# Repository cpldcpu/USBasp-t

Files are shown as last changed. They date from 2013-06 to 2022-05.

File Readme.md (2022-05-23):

## micro - USBasp ##

This is a work in progress. 

* Port of USBasp to ATtiny 85
* Design of optimized hardware

Why?

* It's fun.
* USBasp is a de-facto standard for small USB-AVR programmers. It's the only one to support TPI.
* Porting it to ATtiny85 allows for a smaller and cheaper circuit. Cheaper MCU, no Xtal, etc...

This software is based on Thomas Fischl's USBasp. See readme.txt for original comments.

### Status ####

Software:

* USBasp sucessfully compiles for the ATTiny85.
* micronucleus works as a bootloader.
* USB device is recognized as USBasp and communicates with AVRdude.
* Software tested on microUSB hardware. Both TPI and SPI seem to work.

Hardware:

* Revision 0.5 sent to OSH park for pcb manufacturing.
* Update v1.1 done, ready for manufacturing.
* Update 02/08/2013: All parts received, first device built.

### Flashing

* Flash micronucleus
* Set the fuses as in thuis Makefile: HFUSE=0x5d, LFUSE=0xe1, EFUSE=0xfe
* Flash the firmware with micronucleus

### Hardware ###

Circuit:  
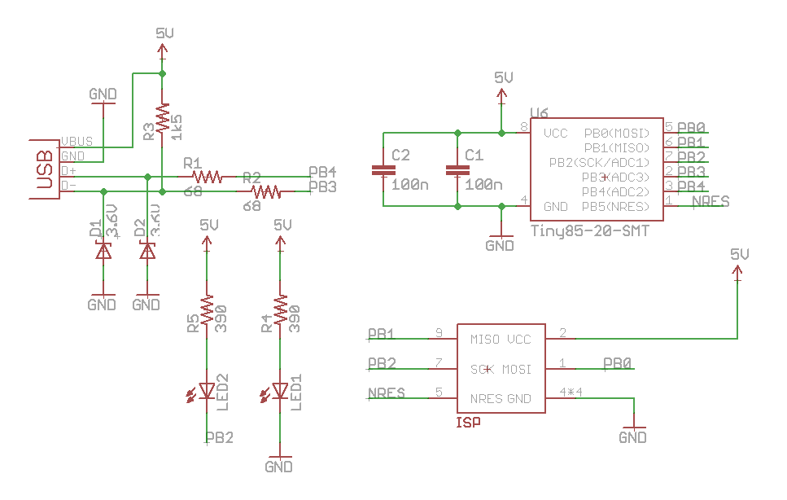
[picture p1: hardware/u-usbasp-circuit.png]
Circuit


v1.1 PCB front side:  
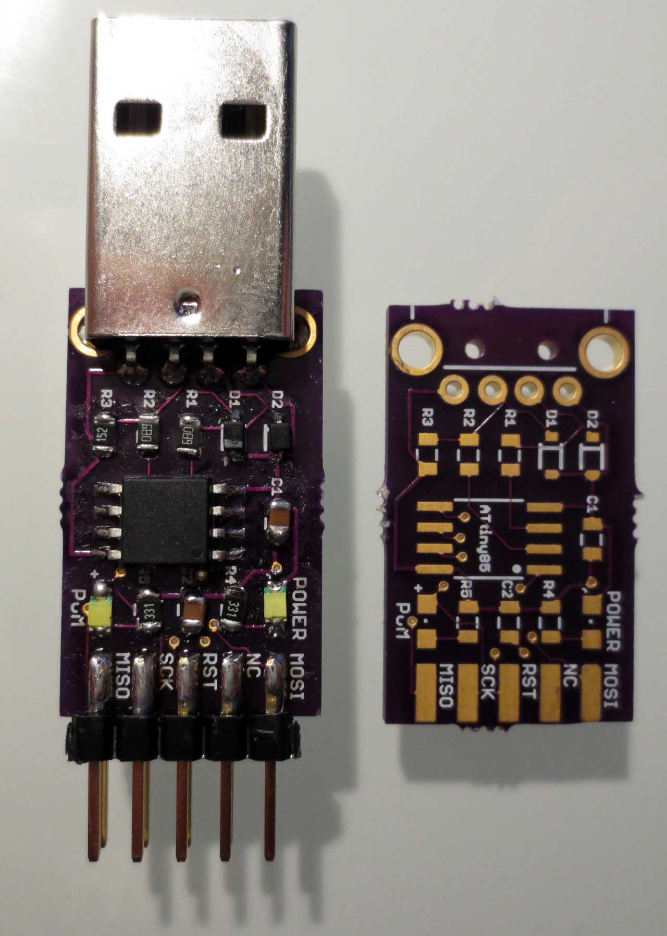
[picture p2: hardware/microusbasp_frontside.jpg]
V1.1 PCB front


v1.1 PCB rear side:   
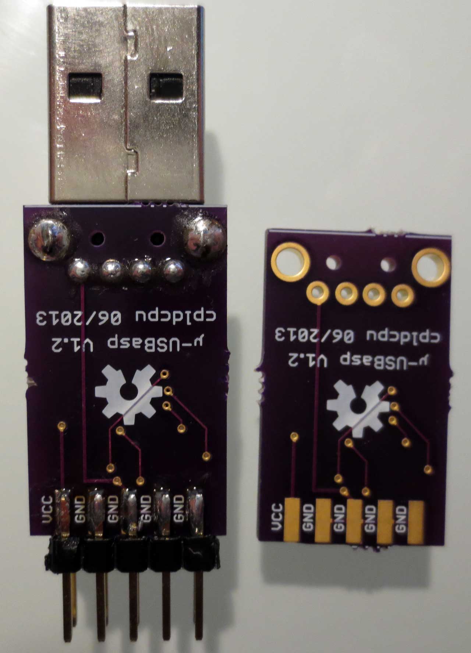
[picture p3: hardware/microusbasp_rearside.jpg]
V1.1 PCB rear


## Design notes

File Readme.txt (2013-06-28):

This is the README file for USBasp.

USBasp is a USB in-circuit programmer for Atmel AVR controllers. It simply
consists of an ATMega88 or an ATMega8 and a couple of passive components.
The programmer uses a firmware-only USB driver, no special USB controller
is needed.

Features:
- Works under multiple platforms. Linux, Mac OS X and Windows are tested.
- No special controllers or smd components are needed.
- Programming speed is up to 5kBytes/sec.
- SCK option to support targets with low clock speed (< 1,5MHz).
- Planned: serial interface to target (e.g. for debugging).

LICENSE

USBasp is distributed under the terms and conditions of the GNU GPL version
2 (see "firmware/usbdrv/License.txt" for details).

USBasp is built with V-USB driver by OBJECTIVE DEVELOPMENT GmbH. See
"firmware/usbdrv/" for further information.

LIMITATIONS

Hardware:
This package includes a circuit diagram. This circuit can only be used for
programming 5V target systems. For other systems a level converter is needed.

Firmware:
The firmware dosn't support USB Suspend Mode. A bidirectional serial
interface to slave exists in hardware but the firmware doesn't support it yet.

USE PRECOMPILED VERSION

Firmware:
Flash "bin/firmware/usbasp.atmega88.xxxx-xx-xx.hex" or
"bin/firmware/usbasp.atmega8.xxxx-xx-xx.hex" to the used controller with a
working programmer (e.g. with avrdude, uisp, ...). Set jumper J2 to activate
USBasp firmware update function.
You have to change the fuse bits for external crystal (see "make fuses").
# TARGET=atmega8    HFUSE=0xc9  LFUSE=0xef
# TARGET=atmega48   HFUSE=0xdd  LFUSE=0xff
# TARGET=atmega88   HFUSE=0xdd  LFUSE=0xff

Windows:
Start Windows and connect USBasp to the system. When Windows asks for a
driver, choose "bin/win-driver". On Win2k and WinXP systems, Windows will
warn that the driver is is not 'digitally signed'. Ignore this message and
continue with the installation.
Now you can run avrdude. Examples:
1. Enter terminal mode with an AT90S2313 connected to the programmer:
   avrdude -c usbasp -p at90s2313 -t
2. Write main.hex to the flash of an ATmega8:
   avrdude -c usbasp -p atmega8 -U flash:w:main.hex

Setting jumpers:
J1 Power target
   Supply target with 5V (USB voltage). Be careful with this option, the
   circuit isn't protected against short circuit!
J2 Jumper for firmware upgrade (not self-upgradable)
   Set this jumper for flashing the ATMega(4)8 of USBasp with another working
   programmer.
J3 SCK option
   If the target clock is lower than 1,5 MHz, you have to set this jumper.
   Then SCK is scaled down from 375 kHz to about 8 kHz.

BUILDING AND INSTALLING FROM SOURCE CODE

Firmware:
To compile the firmware
1. install the GNU toolchain for AVR microcontrollers (avr-gcc, avr-libc),
2. change directory to firmware/
3. run "make main.hex"
4. flash "main.hex" to the ATMega(4)8. E.g. with uisp or avrdude (check
the Makefile option "make flash"). To flash the firmware you have
to set jumper J2 and connect USBasp to a working programmer.
You have to change the fuse bits for external crystal, (check the Makefile
option "make fuses").

Software (avrdude):
AVRDUDE supports USBasp since version 5.2. 
1. install libusb: http://libusb.sourceforge.net/
2. get latest avrdude release: http://download.savannah.gnu.org/releases/avrdude/
3. cd avrdude-X.X.X
5. configure to your environment:
   ./bootstrap (I had to comment out the two if-blocks which verify the
                installed versions of autoconf and automake)
   ./configure
6. compile and install it:
   make 
   make install

Notes on Windows (Cygwin):
Download libusb-win32-device-bin-x.x.x.x.tar.gz from
http://libusb-win32.sourceforge.net/ and unpack it.
-> copy lib/gcc/libusb.a to lib-path
-> copy include/usb.h to include-path
cd avrdude
./configure LDFLAGS="-static" --enable-versioned-doc=no
make

Notes on Darwin/MacOS X:
after "./configure" I had to edit Makefile:
change "avrdude_CPPFLAGS" to "AM_CPPFLAGS"
(why is this needed only on mac? bug in configure.ac?)

Notes on Linux:
To use USBasp as non-root, you have to define some device rules. See
bin/linux-nonroot for an example.

FILES IN THE DISTRIBUTION

Readme.txt ...................... The file you are currently reading
firmware ........................ Source code of the controller firmware
firmware/usbdrv ................. AVR USB driver by Objective Development
firmware/usbdrv/License.txt ..... Public license for AVR USB driver and USBasp
circuit ......................... Circuit diagram in PDF and EAGLE format
bin ............................. Precompiled programs
bin/win-driver .................. Windows driver
bin/firmware .................... Precompiled firmware
bin/linux-nonroot ............... Linux device rule file

MORE INFORMATION

For more information on USBasp and it's components please visit the
following URLs:

USBasp .......................... http://www.fischl.de/usbasp/

Firmware-only V-USB driver ...... http://www.obdev.at/products/vusb/
avrdude ......................... http://www.nongnu.org/avrdude/
libusb .......................... http://libusb.sourceforge.net/
libusb-win32 .................... http://libusb-win32.sourceforge.net/

2011-05-28 Thomas Fischl <tfischl@gmx.de>
http://www.fischl.de

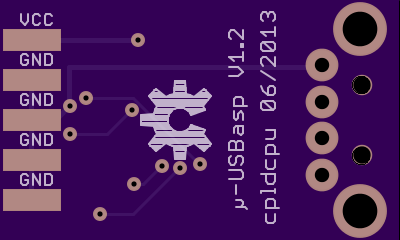
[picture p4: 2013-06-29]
hardware/board_bottom_osh_park.png

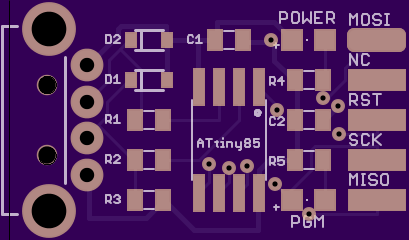
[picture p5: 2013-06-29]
hardware/board_top_osh_park.png

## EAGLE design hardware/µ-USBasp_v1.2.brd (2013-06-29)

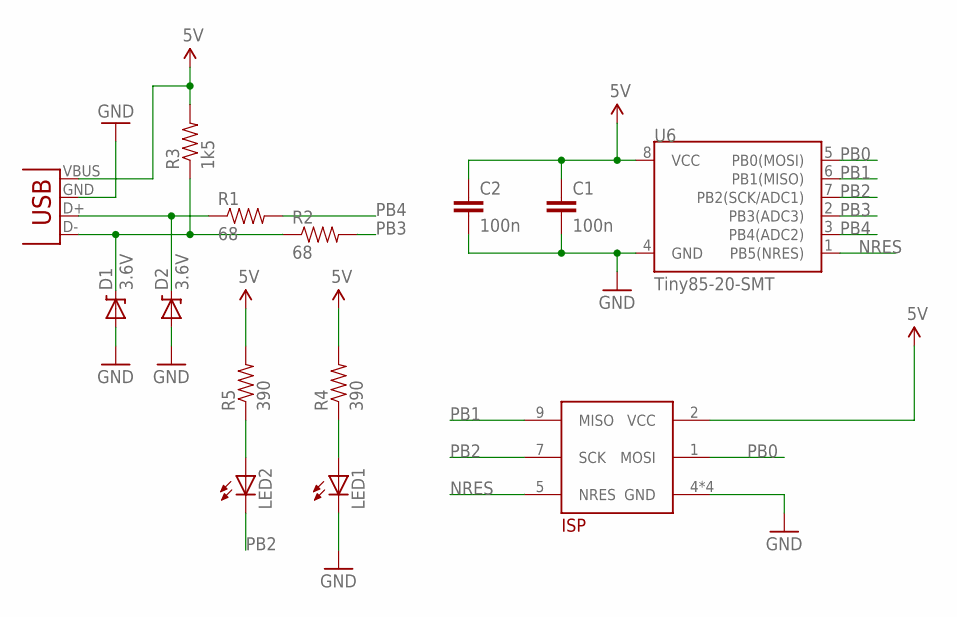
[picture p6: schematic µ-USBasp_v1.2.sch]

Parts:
C1, C2: 100n; 0805
D1, D2: 3.6V; SOD-323
JP2: USB-A-H
LED1, LED2: LEDCHIPLED_0805; CHIPLED_0805
R1, R2: 68; 0805
R3: 1k5; 0805
R4, R5: 390; 0805
U6: Tiny85-20-SMT; SO08-EIAJ
U$1: TB_ISPEDGE_2X5_LONG; ISP_EDGE2X5_LONG

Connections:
5V: C1.1, C2.1, JP2.VBUS (GND), R3.2, R4.2, R5.2, U6.8 (VCC), U$1.2 (VCC)
GND: C1.2, C2.2, D1.2 (A), D2.2 (A), JP2.GND (VBUS), LED1.C, U6.4 (GND), U$1.4 (GND), U$1.6 (GND), U$1.8 (GND), U$1.10 (GND)
unnamed: D1.1 (C), JP2.D- (D+), R2.1, R3.1
unnamed: D2.1 (C), JP2.D+ (D-), R1.1
unnamed: LED1.A, R4.1
unnamed: LED2.A, R5.1
NRES: U6.1 (PB5(NRES)), U$1.5 (NRES)
PB0: U6.5 (PB0(MOSI)), U$1.1 (MOSI)
PB1: U6.6 (PB1(MISO)), U$1.9 (MISO)
PB2: LED2.C, U6.7 (PB2(SCK/ADC1)), U$1.7 (SCK)
PB3: R2.2, U6.2 (PB3(ADC3))
PB4: R1.2, U6.3 (PB4(ADC2))

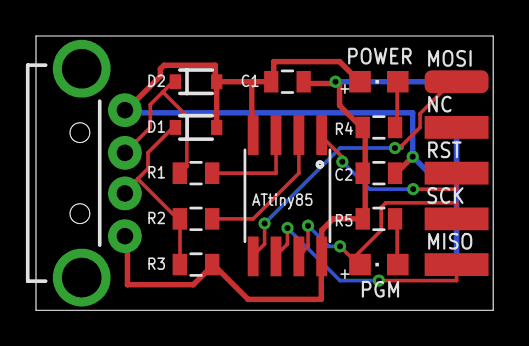
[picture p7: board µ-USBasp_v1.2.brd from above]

Board: 2 copper layers, 25.4 x 15.2 mm, 15 parts (1 on the bottom side), 12 nets.

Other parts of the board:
U$2: OSHW-LOGO-M

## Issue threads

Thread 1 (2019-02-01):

is really work for attiny85?

rizqiuhuy, 2019-02-01:
i try with uploading the firmware to attiny85 with command make flash and make fuses... when try plug the usb it say that usb device descriptor failed ...

rizqiuhuy, 2019-02-02:
okay thanks the problem is the fuse setting bit in makefile is wrong ... is should be lfuse 0xE1 and hfuse 0x5d

Closed 2019-03-13.

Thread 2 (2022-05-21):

fuses

pimium, 2022-05-21:
Hi,

what is the fuses to use. The settings in the Makefile (HFUSE=0xc9, LFUSE=0xef)  are obviously wrong. Then after the CPU ist closed and need and Chrystal.

Thank you in advance

Olivier Pimi

pimium, 2022-05-23:
The fuses make any sens in the makefile. The fuses is set in micronucleos.

Closed 2022-05-23.

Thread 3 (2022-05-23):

USBasp-t can even read the fuses

pimium, 2022-05-23:
Hi, I compiled USBasp-t for an Attiny85. flash micronucleos on the IC, then with micronucleos I flash the USBasp-t application.

I'am seeing with lusb that the usbasp is connected to my PC. But I can't read the fuses of an another attiny85 device. I need help.

Olivier

cpldcpu, 2022-05-23:
I have not touched this project for a long time, so I can only support from memory.

First step should be to ID the device to check whether programmer and device are connected. Does that work?

pimium, 2022-05-23:
I'm seing the programmer connected to the PC with lsusb. When I try to read the fuses with the avrdude, avrdude sent a message like "Couldn't set the clock or find the device". I think the Reset-Pin isn't pull down.
I'll check it further today in the evening.
Olivier

pimium, 2022-05-23:
The reset pin has to be defined as normal pin in the fuses setting.

Closed 2022-05-23.

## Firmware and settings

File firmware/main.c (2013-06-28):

/*
 * USBasp - USB in-circuit programmer for Atmel AVR controllers
 *
 * Thomas Fischl <tfischl@gmx.de>
 *
 * License........: GNU GPL v2 (see Readme.txt)
 * Target.........: ATMega8 at 12 MHz
 * Creation Date..: 2005-02-20
 * Last change....: 2009-02-28
 *
 * PC2 SCK speed option.
 * GND  -> slow (8khz SCK),
 * open -> software set speed (default is 375kHz SCK)
 */

#include <avr/io.h>
#include <avr/interrupt.h>
#include <avr/pgmspace.h>
#include <avr/wdt.h>
#include <avr/eeprom.h>
#include <util/delay.h>

#include "usbasp.h"
#include "usbdrv.h"
#include "isp.h"
#include "clock.h"
#include "tpi.h"
#include "tpi_defs.h"

static uchar replyBuffer[8];

static uchar prog_state = PROG_STATE_IDLE;
static uchar prog_sck = USBASP_ISP_SCK_AUTO;

static uchar prog_address_newmode = 0;
static unsigned long prog_address;
static unsigned int prog_nbytes = 0;
static unsigned int prog_pagesize;
static uchar prog_blockflags;
static uchar prog_pagecounter;

uchar usbFunctionSetup(uchar data[8]) {

	uchar len = 0;

	if (data[1] == USBASP_FUNC_CONNECT) {

		/* set SCK speed */
#ifndef __AVR_ATtiny85__		
		if ((PINC & (1 << PC2)) == 0) {
			ispSetSCKOption(USBASP_ISP_SCK_8);
		} else {
			ispSetSCKOption(prog_sck);
		}
#else
		ispSetSCKOption(prog_sck);
#endif
		/* set compatibility mode of address delivering */
		prog_address_newmode = 0;

		ledRedOn();
		ispConnect();

	} else if (data[1] == USBASP_FUNC_DISCONNECT) {
		ispDisconnect();
		ledRedOff();

	} else if (data[1] == USBASP_FUNC_TRANSMIT) {
		replyBuffer[0] = ispTransmit(data[2]);
		replyBuffer[1] = ispTransmit(data[3]);
		replyBuffer[2] = ispTransmit(data[4]);
		replyBuffer[3] = ispTransmit(data[5]);
		len = 4;

	} else if (data[1] == USBASP_FUNC_READFLASH) {

		if (!prog_address_newmode)
			prog_address = (data[3] << 8) | data[2];

		prog_nbytes = (data[7] << 8) | data[6];
		prog_state = PROG_STATE_READFLASH;
		len = 0xff; /* multiple in */

	} else if (data[1] == USBASP_FUNC_READEEPROM) {

		if (!prog_address_newmode)
			prog_address = (data[3] << 8) | data[2];

		prog_nbytes = (data[7] << 8) | data[6];
		prog_state = PROG_STATE_READEEPROM;
		len = 0xff; /* multiple in */

	} else if (data[1] == USBASP_FUNC_ENABLEPROG) {
		replyBuffer[0] = ispEnterProgrammingMode();
		len = 1;

	} else if (data[1] == USBASP_FUNC_WRITEFLASH) {

		if (!prog_address_newmode)
			prog_address = (data[3] << 8) | data[2];

		prog_pagesize = data[4];
		prog_blockflags = data[5] & 0x0F;
		prog_pagesize += (((unsigned int) data[5] & 0xF0) << 4);
		if (prog_blockflags & PROG_BLOCKFLAG_FIRST) {
			prog_pagecounter = prog_pagesize;
		}
		prog_nbytes = (data[7] << 8) | data[6];
		prog_state = PROG_STATE_WRITEFLASH;
		len = 0xff; /* multiple out */

	} else if (data[1] == USBASP_FUNC_WRITEEEPROM) {

		if (!prog_address_newmode)
			prog_address = (data[3] << 8) | data[2];

		prog_pagesize = 0;
		prog_blockflags = 0;
		prog_nbytes = (data[7] << 8) | data[6];
		prog_state = PROG_STATE_WRITEEEPROM;
		len = 0xff; /* multiple out */

	} else if (data[1] == USBASP_FUNC_SETLONGADDRESS) {

		/* set new mode of address delivering (ignore address delivered in commands) */
		prog_address_newmode = 1;
		/* set new address */
		prog_address = *((unsigned long*) &data[2]);

	} else if (data[1] == USBASP_FUNC_SETISPSCK) {

		/* set sck option */
		prog_sck = data[2];
		replyBuffer[0] = 0;
		len = 1;

	} else if (data[1] == USBASP_FUNC_TPI_CONNECT) {
		tpi_dly_cnt = data[2] | (data[3] << 8);

		/* RST high */
		ISP_OUT |= (1 << ISP_RST);
		ISP_DDR |= (1 << ISP_RST);

		clockWait(3);

		/* RST low */
		ISP_OUT &= ~(1 << ISP_RST);
		ledRedOn();

		clockWait(16);
		tpi_init();
	
	} else if (data[1] == USBASP_FUNC_TPI_DISCONNECT) {

		tpi_send_byte(TPI_OP_SSTCS(TPISR));
		tpi_send_byte(0);

		clockWait(10);

		/* pulse RST */
		ISP_OUT |= (1 << ISP_RST);
		clockWait(5);
		ISP_OUT &= ~(1 << ISP_RST);
		clockWait(5);

		/* set all ISP pins inputs */
		ISP_DDR &= ~((1 << ISP_RST) | (1 << ISP_SCK) | (1 << ISP_MOSI));
		/* switch pullups off */
		ISP_OUT &= ~((1 << ISP_RST) | (1 << ISP_SCK) | (1 << ISP_MOSI));

		ledRedOff();
	
	} else if (data[1] == USBASP_FUNC_TPI_RAWREAD) {
		replyBuffer[0] = tpi_recv_byte();
		len = 1;
	
	} else if (data[1] == USBASP_FUNC_TPI_RAWWRITE) {
		tpi_send_byte(data[2]);
	
	} else if (data[1] == USBASP_FUNC_TPI_READBLOCK) {
		prog_address = (data[3] << 8) | data[2];
		prog_nbytes = (data[7] << 8) | data[6];
		prog_state = PROG_STATE_TPI_READ;
		len = 0xff; /* multiple in */
	
	} else if (data[1] == USBASP_FUNC_TPI_WRITEBLOCK) {
		prog_address = (data[3] << 8) | data[2];
		prog_nbytes = (data[7] << 8) | data[6];
		prog_state = PROG_STATE_TPI_WRITE;
		len = 0xff; /* multiple out */
	
	} else if (data[1] == USBASP_FUNC_GETCAPABILITIES) {
		replyBuffer[0] = USBASP_CAP_0_TPI;
		replyBuffer[1] = 0;
		replyBuffer[2] = 0;
		replyBuffer[3] = 0;
		len = 4;
	}

	usbMsgPtr = replyBuffer;

	return len;
}

uchar usbFunctionRead(uchar *data, uchar len) {

	uchar i;

	/* check if programmer is in correct read state */
	if ((prog_state != PROG_STATE_READFLASH) && (prog_state
			!= PROG_STATE_READEEPROM) && (prog_state != PROG_STATE_TPI_READ)) {
		return 0xff;
	}

	/* fill packet TPI mode */
	if(prog_state == PROG_STATE_TPI_READ)
	{
		tpi_read_block(prog_address, data, len);
		prog_address += len;
		return len;
	}

	/* fill packet ISP mode */
	for (i = 0; i < len; i++) {
		if (prog_state == PROG_STATE_READFLASH) {
			data[i] = ispReadFlash(prog_address);
		} else {
			data[i] = ispReadEEPROM(prog_address);
		}
		prog_address++;
	}

	/* last packet? */
	if (len < 8) {
		prog_state = PROG_STATE_IDLE;
	}

	return len;
}

uchar usbFunctionWrite(uchar *data, uchar len) {

	uchar retVal = 0;
	uchar i;

	/* check if programmer is in correct write state */
	if ((prog_state != PROG_STATE_WRITEFLASH) && (prog_state
			!= PROG_STATE_WRITEEEPROM) && (prog_state != PROG_STATE_TPI_WRITE)) {
		return 0xff;
	}

	if (prog_state == PROG_STATE_TPI_WRITE)
	{
		tpi_write_block(prog_address, data, len);
		prog_address += len;
		prog_nbytes -= len;
		if(prog_nbytes <= 0)
		{
			prog_state = PROG_STATE_IDLE;
			return 1;
		}
		return 0;
	}

	for (i = 0; i < len; i++) {

		if (prog_state == PROG_STATE_WRITEFLASH) {
			/* Flash */

			if (prog_pagesize == 0) {
				/* not paged */
				ispWriteFlash(prog_address, data[i], 1);
			} else {
				/* paged */
				ispWriteFlash(prog_address, data[i], 0);
				prog_pagecounter--;
				if (prog_pagecounter == 0) {
					ispFlushPage(prog_address, data[i]);
					prog_pagecounter = prog_pagesize;
				}
			}

		} else {
			/* EEPROM */
			ispWriteEEPROM(prog_address, data[i]);
		}

		prog_nbytes--;

		if (prog_nbytes == 0) {
			prog_state = PROG_STATE_IDLE;
			if ((prog_blockflags & PROG_BLOCKFLAG_LAST) && (prog_pagecounter
					!= prog_pagesize)) {

				/* last block and page flush pending, so flush it now */
				ispFlushPage(prog_address, data[i]);
			}

			retVal = 1; // Need to return 1 when no more data is to be received
		}

		prog_address++;
	}

	return retVal;
}

 #ifdef __AVR_ATtiny85__	
/* ------------------------------------------------------------------------- */
/* ------------------------ Oscillator Calibration ------------------------- */
/* ------------------------------------------------------------------------- */

/* Calibrate the RC oscillator to 8.25 MHz. The core clock of 16.5 MHz is
 * derived from the 66 MHz peripheral clock by dividing. Our timing reference
 * is the Start Of Frame signal (a single SE0 bit) available immediately after
 * a USB RESET. We first do a binary search for the OSCCAL value and then
 * optimize this value with a neighboorhod search.
 * This algorithm may also be used to calibrate the RC oscillator directly to
 * 12 MHz (no PLL involved, can therefore be used on almost ALL AVRs), but this
 * is wide outside the spec for the OSCCAL value and the required precision for
 * the 12 MHz clock! Use the RC oscillator calibrated to 12 MHz for
 * experimental purposes only!
 */
static void calibrateOscillator(void)
{
uchar       step = 128;
uchar       trialValue = 0, optimumValue;
int         x, optimumDev, targetValue = (unsigned)(1499 * (double)F_CPU / 10.5e6 + 0.5);

    /* do a binary search: */
    do{
        OSCCAL = trialValue + step;
        x = usbMeasureFrameLength();    /* proportional to current real frequency */
        if(x < targetValue)             /* frequency still too low */
            trialValue += step;
        step >>= 1;
    }while(step > 0);
    /* We have a precision of +/- 1 for optimum OSCCAL here */
    /* now do a neighborhood search for optimum value */
    optimumValue = trialValue;
    optimumDev = x; /* this is certainly far away from optimum */
    for(OSCCAL = trialValue - 1; OSCCAL <= trialValue + 1; OSCCAL++){
        x = usbMeasureFrameLength() - targetValue;
        if(x < 0)
            x = -x;
        if(x < optimumDev){
            optimumDev = x;
            optimumValue = OSCCAL;
        }
    }
    OSCCAL = optimumValue; 
}

void usbEventResetReady(void)
{
    calibrateOscillator();
    eeprom_write_byte(0, OSCCAL);   /* store the calibrated value in EEPROM */
}
#endif
/* ------------------------------------------------------------------------- */
/* --------------------------------- main ---------------------------------- */
/* ------------------------------------------------------------------------- */

int main(void) {
	uchar i, j;
	uchar   calibrationValue;

	/* no pullups on USB and ISP pins */
#ifndef __AVR_ATtiny85__		
	PORTD = 0;
#endif	
	PORTB = 0;
	/* all outputs except PD2 = INT0 */
#ifndef __AVR_ATtiny85__		
	DDRD = ~(1 << 2);

	/* output SE0 for USB reset */
	DDRB = ~0;
	j = 0;
	
	/* USB Reset by device only required on Watchdog Reset */
	while (--j) {
		i = 0;
		/* delay >10ms for USB reset */
		while (--i)
			;
	}
	
#else
    calibrationValue = eeprom_read_byte(0); /* calibration value from last time */
    if(calibrationValue != 0xff){
        OSCCAL = calibrationValue;
    }
    
    usbDeviceDisconnect();
    for(i=0;i<20;i++){  /* 300 ms disconnect */
        _delay_ms(15);
    }
    usbDeviceConnect();
#endif	
	
	/* all USB and ISP pins inputs */
	DDRB = 0;

#ifndef __AVR_ATtiny85__	
	/* all inputs except PC0, PC1 */
	DDRC = 0x03;
	PORTC = 0xfe;
#endif
	// no leds on attiny85


	/* init timer */
	clockInit();

	/* main event loop */
	usbInit();
	sei();
	for (;;) {
		usbPoll();
	}
	return 0;
}

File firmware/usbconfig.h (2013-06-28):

/* Name: usbconfig.h
 * Project: AVR USB driver
 * Author: Christian Starkjohann, Thomas Fischl
 * Creation Date: 2005-04-01
 * Tabsize: 4
 * Copyright: (c) 2005 by OBJECTIVE DEVELOPMENT Software GmbH
 * License: GNU GPL v2 (see License.txt) or proprietary (CommercialLicense.txt)
 */

#ifndef __usbconfig_h_included__
#define __usbconfig_h_included__

/*
General Description:
This file contains parts of the USB driver which can be configured and can or
must be adapted to your hardware.

Please note that the usbdrv contains a usbconfig-prototype.h file now. We
recommend that you use that file as a template because it will always list
the newest features and options.
*/

/* ---------------------------- Hardware Config ---------------------------- */

#define USB_CFG_IOPORTNAME      B
/* This is the port where the USB bus is connected. When you configure it to
 * "B", the registers PORTB, PINB and DDRB will be used.
 */

#ifndef __AVR_ATtiny85__	
	#define USB_CFG_DMINUS_BIT      0
#else
	#define USB_CFG_DMINUS_BIT      3
#endif
	
/* This is the bit number in USB_CFG_IOPORT where the USB D- line is connected.
 * This may be any bit in the port.
 */
 
#ifndef __AVR_ATtiny85__	
	#define USB_CFG_DPLUS_BIT       1
#else
	#define USB_CFG_DPLUS_BIT      4
#endif
	
/* This is the bit number in USB_CFG_IOPORT where the USB D+ line is connected.
 * This may be any bit in the port. Please note that D+ must also be connected
 * to interrupt pin INT0!
 */
#define USB_CFG_CLOCK_KHZ (F_CPU/1000)
/* Clock rate of the AVR in MHz. Legal values are 12000, 16000 or 16500.
 * The 16.5 MHz version of the code requires no crystal, it tolerates +/- 1%
 * deviation from the nominal frequency. All other rates require a precision
 * of 2000 ppm and thus a crystal!
 * Default if not specified: 12 MHz
 */

/* ----------------------- Optional Hardware Config ------------------------ */

/* #define USB_CFG_PULLUP_IOPORTNAME   D */
/* If you connect the 1.5k pullup resistor from D- to a port pin instead of
 * V+, you can connect and disconnect the device from firmware by calling
 * the macros usbDeviceConnect() and usbDeviceDisconnect() (see usbdrv.h).
 * This constant defines the port on which the pullup resistor is connected.
 */
/* #define USB_CFG_PULLUP_BIT          4 */
/* This constant defines the bit number in USB_CFG_PULLUP_IOPORT (defined
 * above) where the 1.5k pullup resistor is connected. See description
 * above for details.
 */

/* --------------------------- Functional Range ---------------------------- */

#define USB_CFG_HAVE_INTRIN_ENDPOINT    0
/* Define this to 1 if you want to compile a version with two endpoints: The
 * default control endpoint 0 and an interrupt-in endpoint 1.
 */
#define USB_CFG_HAVE_INTRIN_ENDPOINT3   0
/* Define this to 1 if you want to compile a version with three endpoints: The
 * default control endpoint 0, an interrupt-in endpoint 1 and an interrupt-in
 * endpoint 3. You must also enable endpoint 1 above.
 */
#define USB_CFG_IMPLEMENT_HALT          0
/* Define this to 1 if you also want to implement the ENDPOINT_HALT feature
 * for endpoint 1 (interrupt endpoint). Although you may not need this feature,
 * it is required by the standard. We have made it a config option because it
 * bloats the code considerably.
 */
#define USB_CFG_INTR_POLL_INTERVAL      10
/* If you compile a version with endpoint 1 (interrupt-in), this is the poll
 * interval. The value is in milliseconds and must not be less than 10 ms for
 * low speed devices.
 */
#define USB_CFG_IS_SELF_POWERED         0
/* Define this to 1 if the device has its own power supply. Set it to 0 if the
 * device is powered from the USB bus.
 */
#define USB_CFG_MAX_BUS_POWER           50
/* Set this variable to the maximum USB bus power consumption of your device.
 * The value is in milliamperes. [It will be divided by two since USB
 * communicates power requirements in units of 2 mA.]
 */
#define USB_CFG_IMPLEMENT_FN_WRITE      1
/* Set this to 1 if you want usbFunctionWrite() to be called for control-out
 * transfers. Set it to 0 if you don't need it and want to save a couple of
 * bytes.
 */
#define USB_CFG_IMPLEMENT_FN_READ       1
/* Set this to 1 if you need to send control replies which are generated
 * "on the fly" when usbFunctionRead() is called. If you only want to send
 * data from a static buffer, set it to 0 and return the data from
 * usbFunctionSetup(). This saves a couple of bytes.
 */
#define USB_CFG_IMPLEMENT_FN_WRITEOUT   0
/* Define this to 1 if you want to use interrupt-out (or bulk out) endpoint 1.
 * You must implement the function usbFunctionWriteOut() which receives all
 * interrupt/bulk data sent to endpoint 1.
 */
#define USB_CFG_HAVE_FLOWCONTROL        0
/* Define this to 1 if you want flowcontrol over USB data. See the definition
 * of the macros usbDisableAllRequests() and usbEnableAllRequests() in
 * usbdrv.h.
 */

 
 #ifndef __ASSEMBLER__
	extern void usbEventResetReady(void);
#endif
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

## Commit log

2013-06-28 First version of USBasp-t85 for ATtiny85
    USB Works, actual programming yet untested.
    No hardware SPI Support
    No LEDs
2013-06-29 PCB design
    [µ-USBasp_v1.1.brd, µ-USBasp_v1.1.sch]
2013-06-29 Board v1.2
    [µ-USBasp_v1.2.brd, µ-USBasp_v1.2.sch]
2022-05-23 update fuses and add gitignore
2022-05-23 add the extended fuses to the makefile

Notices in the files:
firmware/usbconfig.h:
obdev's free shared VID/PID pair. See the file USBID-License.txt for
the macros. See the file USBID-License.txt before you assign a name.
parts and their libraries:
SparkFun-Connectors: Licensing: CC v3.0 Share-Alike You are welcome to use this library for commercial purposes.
